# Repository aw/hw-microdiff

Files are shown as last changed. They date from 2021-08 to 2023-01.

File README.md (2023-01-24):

# μDiff: 10mbps over 1km on a single pair of wires

A simple 46mmx22.5mm module to route power and differential signals (RS-485) over RJ-45.

Stacked modules

This project is also described in detail [on Hackaday.io](https://hackaday.io/project/179020-10mbps-over-1km-on-a-single-pair-of-wires)

It can be purchased as a kit **[from Tindie](https://www.tindie.com/products/24510/)**

 

This project is [certified open hardware](https://certification.oshwa.org/jp000009.html):

OSHW_mark_JP000009 (https://certification.oshwa.org/jp000009.html)

# How it works

μDiff provides an easy way to reliably transfer power and a digital signal over a long-distance using an inexpensive RJ-45 cable.

[Watch a demo](
https://www.youtube.com/watch?v=i-OBXi-Fx-U)

It uses RS-485 differential signaling and 802.3af Power-over-Ethernet pinouts to achieve this. It can accept an input voltage between 6.5V-12V, and provides outputs of 5V and 3.3V. All signals and voltages can be accessed through a 10-pin header. 

Current is limited to 1A. Beware of current limitations on the RJ-45 cable, it's typically ~350mA for an AWG26 shielded wire. 

# PCB features

  * Form factor 46mm x 22.5mm
  * Lead-free, RoHS compliant
  * Stackable with 4xM2 holes (1x grounded)
  * Open Source Hardware under [CC BY-SA 4.0](#License)
  * Easy to source off-the-shelf through-hole components
  * On-board (SMD 0603, 0805) capacitors, resistors, and diodes
  * Solder bridge jumpers to enable fail-safe biasing, termination, grounding.

board-v05

### Top view

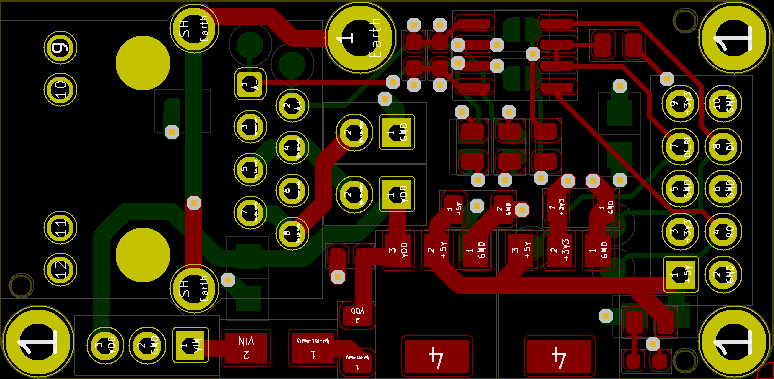
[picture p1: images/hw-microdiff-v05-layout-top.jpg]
PCB Top


### Bottom view

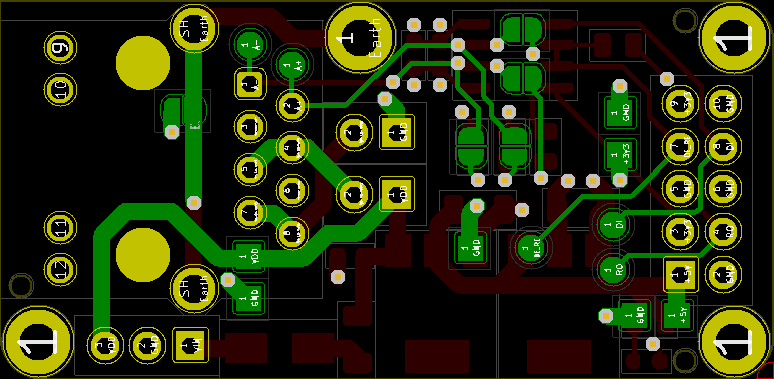
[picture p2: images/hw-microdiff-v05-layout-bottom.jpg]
PCB Bottom


See [images](images/) for more views.

# BOM (through-hole)

| Quantity | Item and Description | Datasheet |
| :----: | :---- | :---- |
| 1 | RJ45 Connector | [Assmann-RJ45-connector.pdf](datasheets/Assmann-RJ45-connector.pdf) |
| 1 | 10-pin (2x5) 2.54mm male of female header | |
| 1 | 3-pin (1x3) 2.54mm male or female header | |

# BOM (surface mount)

See [datasheets](datasheets/)

# Schematic

The schematic is available [here](schematic-v05.pdf)

# Notes

This PCB was designed with [Kicad](https://kicad.org/) v6.0 from the `debian buster-backports` repository.

I take no responsibility for any problems that may occur with your use of this PCB or design files. Create and use at your own risk.

# License

μDiff: 10mbps over 1km on a single pair of wires © 2021~ by [Alexander Williams](https://a1w.ca/) is licensed under [_CC BY-SA 4.0_ (Attribution-ShareAlike 4.0 International)](https://creativecommons.org/licenses/by-nc-sa/4.0/).

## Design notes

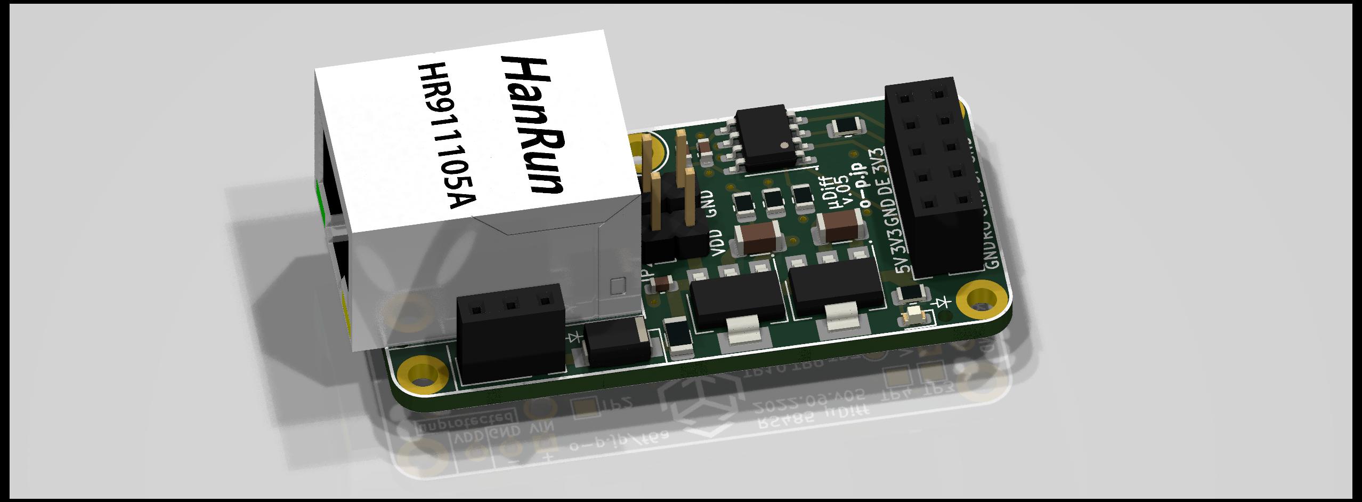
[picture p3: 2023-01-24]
images/hw-microdiff-v05-raytrace2.jpg

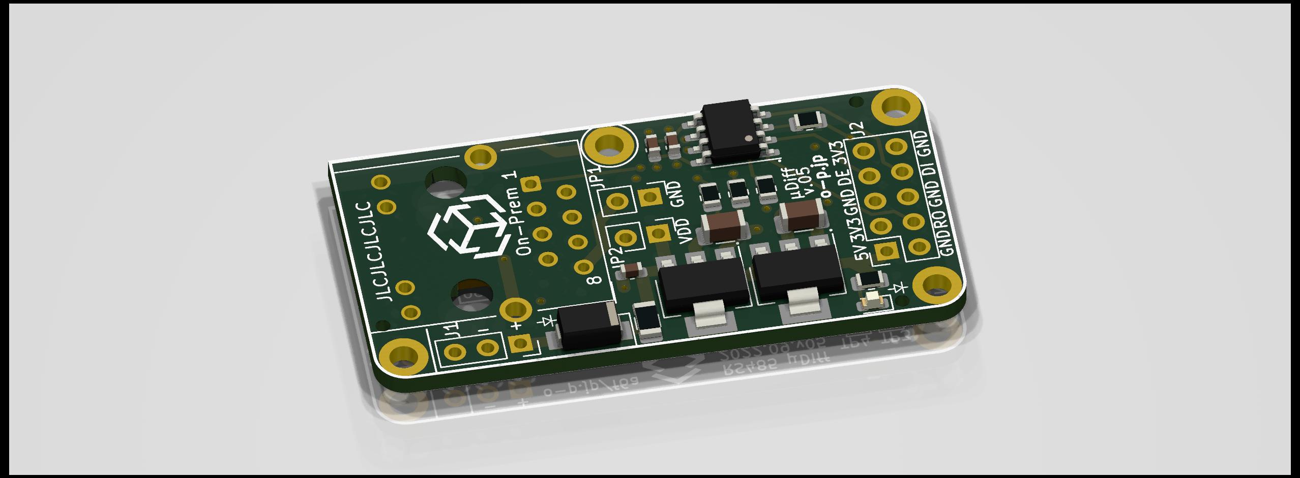
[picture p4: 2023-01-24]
images/hw-microdiff-v05-raytrace1.jpg

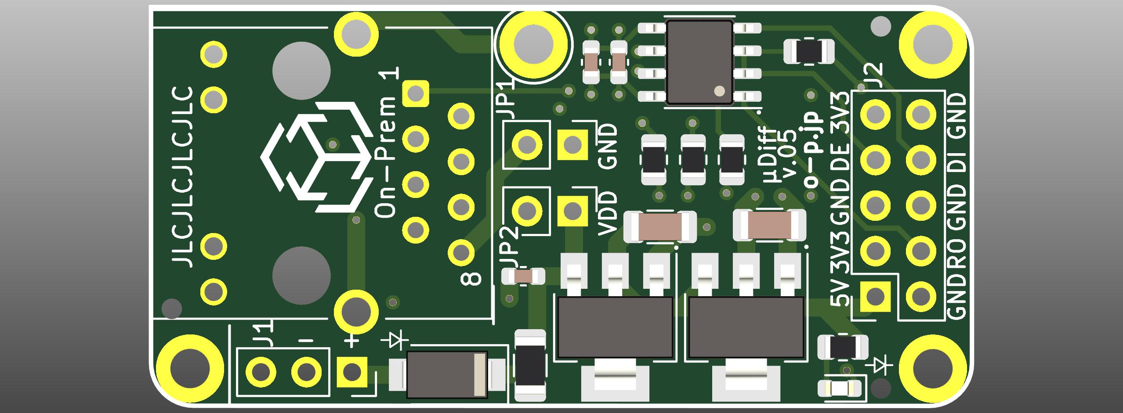
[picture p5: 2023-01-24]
images/hw-microdiff-v05-top-smd.jpg

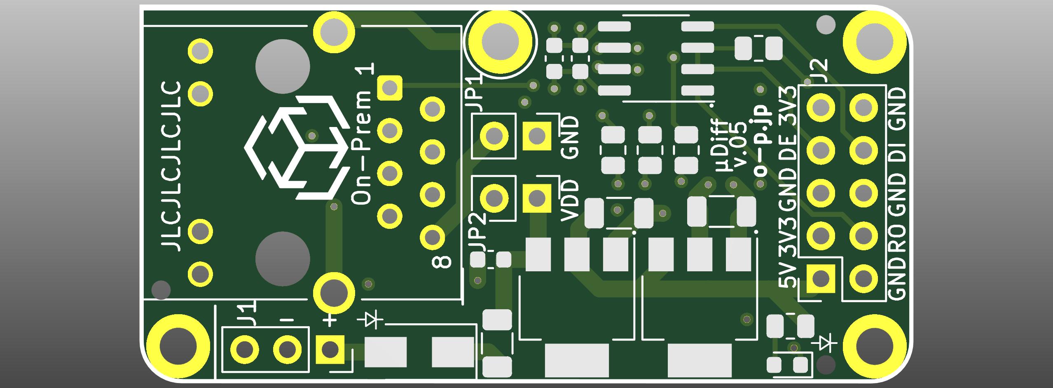
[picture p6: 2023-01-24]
images/hw-microdiff-v05-top.jpg

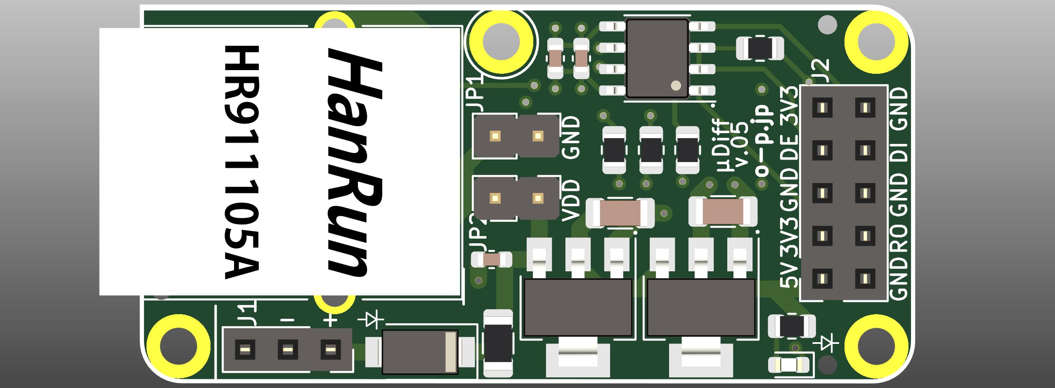
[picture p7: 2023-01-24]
images/hw-microdiff-v05-top-tht-smd.jpg

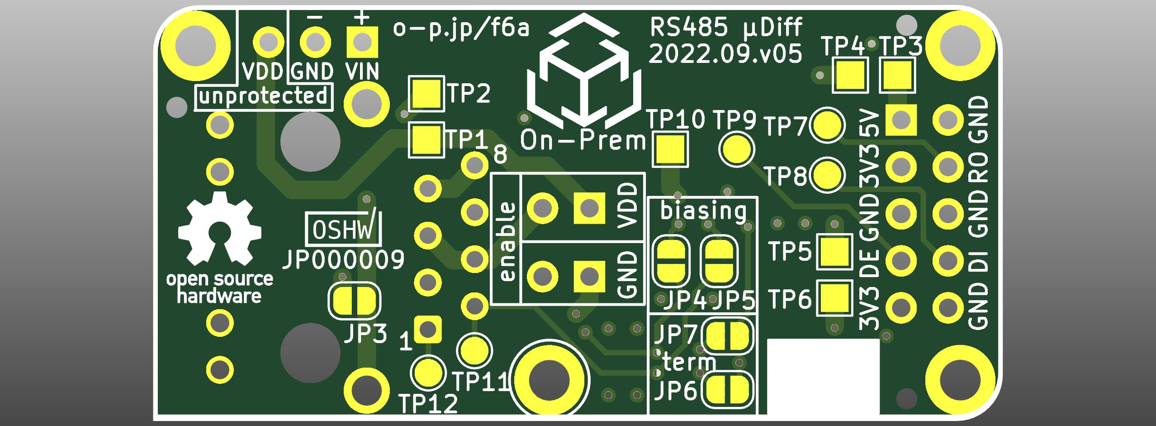
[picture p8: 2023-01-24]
images/hw-microdiff-v05-bottom.jpg

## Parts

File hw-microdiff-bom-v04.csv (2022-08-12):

Comment | Designator | Footprint | LCSC Part #
0.1uF 50V Unpolarized capacitor | C1,C4 | C_0603_1608Metric | C14663
22uF 10V Unpolarized capacitor | C2,C3 | C_1206_3216Metric | C5672
10uF 10V Unpolarized capacitor | C5 | C_0603_1608Metric | C19702
Diode 40V/3A Schottky diode | D1 | D_SMA | C8678
Blue LED Light emitting diode | D2 | LED_0603_1608Metric | C72041
Fuse 24V/1A Fuse | F1 | Fuse_1206_3216Metric | C910830
M3_MountingHole Mounting Hole without connection | H2,H3,H4 | MountingHole_2.2mm_M2_ISO14580_Pad
Power Input Generic connector, single row, 01x02, script generated (kicad-library-utils/schlib/autogen/connector/) | J1 | PinHeader_1x02_P2.54mm_Vertical
Header 2x4P Generic connector, double row, 02x04, odd/even pin numbering scheme (row 1 odd numbers, row 2 even numbers), script generated (kicad-library-utils/schlib/autogen/connector/) | J2 | PinSocket_2x04_P2.54mm_Vertical
8P8C RJ connector, 8P8C (8 positions 8 connected), RJ31/RJ32/RJ33/RJ34/RJ35/RJ41/RJ45/RJ49/RJ61, Shielded | J3 | RJ45_Hanrun_HR911105A
GND EN Jumper, normally open, small symbol | JP1 | PinHeader_1x02_P2.54mm_Vertical
VIN EN Jumper, normally open, small symbol | JP2 | PinHeader_1x02_P2.54mm_Vertical
drive EN Jumper, normally open, small symbol | JP3 | SW_DIP_SPSTx01_Slide_9.78x4.72mm_W7.62mm_P2.54mm
220R Resistor | R1 | R_0805_2012Metric | C17557
10K Resistor | R2,R4,R6,R8 | R_0805_2012Metric
20K Resistor | R3,R7 | R_0805_2012Metric_Pad1.20x1.40mm_HandSolder
120R Resistor | R5 | R_Axial_DIN0207_L6.3mm_D2.5mm_P10.16mm_Horizontal
5V/1A 1A Low Dropout regulator, positive, 5.0V fixed output, SOT-223 | U1 | SOT-223 | C6187
3.3V/1A 1A Low Dropout regulator, positive, 3.3V fixed output, SOT-223 | U2 | SOT-223 | C6186
RS-485 Industrial 3.3V Low Power Half-Duplex RS-485 Transceiver 10Mbps, SOIC-8 | U3 | SOIC-8_3.9x4.9mm_P1.27mm | C8963

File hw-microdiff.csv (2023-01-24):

Comment | Designator | Footprint | LCSC Part #
0.1uF 50V Unpolarized capacitor | C1,C4 | C_0603_1608Metric | C14663
22uF 10V Unpolarized capacitor | C2,C3 | C_1206_3216Metric | C5672
10uF 10V Unpolarized capacitor | C5 | C_0603_1608Metric | C19702
Diode 40V/3A Schottky diode | D1 | D_SMA | C8678
Blue LED Light emitting diode | D2 | LED_0603_1608Metric | C72041
Fuse 24V/1A Fuse | F1 | Fuse_1206_3216Metric | C910830
M2_MountingHole Mounting Hole without connection | H1,H2,H3,H4 | MountingHole_2.2mm_M2_ISO14580_Pad
Power Input Generic connector, single row, 01x03, script generated (kicad-library-utils/schlib/autogen/connector/) | J1 | PinSocket_1x03_P2.54mm_Vertical
Header 2x5P Generic connector, double row, 02x05, odd/even pin numbering scheme (row 1 odd numbers, row 2 even numbers), script generated (kicad-library-utils/schlib/autogen/connector/) | J2 | PinSocket_2x05_P2.54mm_Vertical
8P8C RJ connector, 8P8C (8 positions 8 connected), RJ31/RJ32/RJ33/RJ34/RJ35/RJ41/RJ45/RJ49/RJ61, Shielded | J3 | RJ45_Hanrun_HR911105A
GND EN Jumper, 2-pole, open | JP1 | PinHeader_1x02_P2.54mm_Vertical
VIN EN Jumper, 2-pole, open | JP2 | PinHeader_1x02_P2.54mm_Vertical
Grounding Solder Jumper, 2-pole, open | JP3 | SolderJumper-2_P1.3mm_Open_RoundedPad1.0x1.5mm
Biasing- Solder Jumper, 2-pole, open | JP4 | SolderJumper-2_P1.3mm_Open_RoundedPad1.0x1.5mm
Biasing+ Solder Jumper, 2-pole, open | JP5 | SolderJumper-2_P1.3mm_Open_RoundedPad1.0x1.5mm
Terminating Solder Jumper, 2-pole, open | JP6,JP7 | SolderJumper-2_P1.3mm_Open_RoundedPad1.0x1.5mm
220R Resistor | R1 | R_0805_2012Metric | C17557
10K Resistor | R2 | R_0805_2012Metric | C17414
390R Resistor | R3,R4 | R_0805_2012Metric | C17655
100R Resistor | R5 | R_0805_2012Metric | C17408
TP_VDD test point | TP1 | TestPoint_Pad_1.5x1.5mm
TP_GND test point | TP2,TP4,TP6,TP10 | TestPoint_Pad_1.5x1.5mm
TP_5V test point | TP3 | TestPoint_Pad_1.5x1.5mm
TP_3V3 test point | TP5 | TestPoint_Pad_1.5x1.5mm
TP_RO test point | TP7 | TestPoint_Pad_D1.5mm
TP_DI test point | TP8 | TestPoint_Pad_D1.5mm
TP_DE_RE test point | TP9 | TestPoint_Pad_D1.5mm
TP_A1 test point | TP11 | TestPoint_Pad_D1.5mm
TP_B1 test point | TP12 | TestPoint_Pad_D1.5mm
5V/1A 1A Low Dropout regulator, positive, 5.0V fixed output, SOT-223 | U1 | SOT-223 | C6187
3.3V/1A 1A Low Dropout regulator, positive, 3.3V fixed output, SOT-223 | U2 | SOT-223 | C6186
RS-485 Industrial 3.3V Low Power Half-Duplex RS-485 Transceiver 10Mbps, SOIC-8 | U3 | SOIC-8_3.9x4.9mm_P1.27mm | C8963

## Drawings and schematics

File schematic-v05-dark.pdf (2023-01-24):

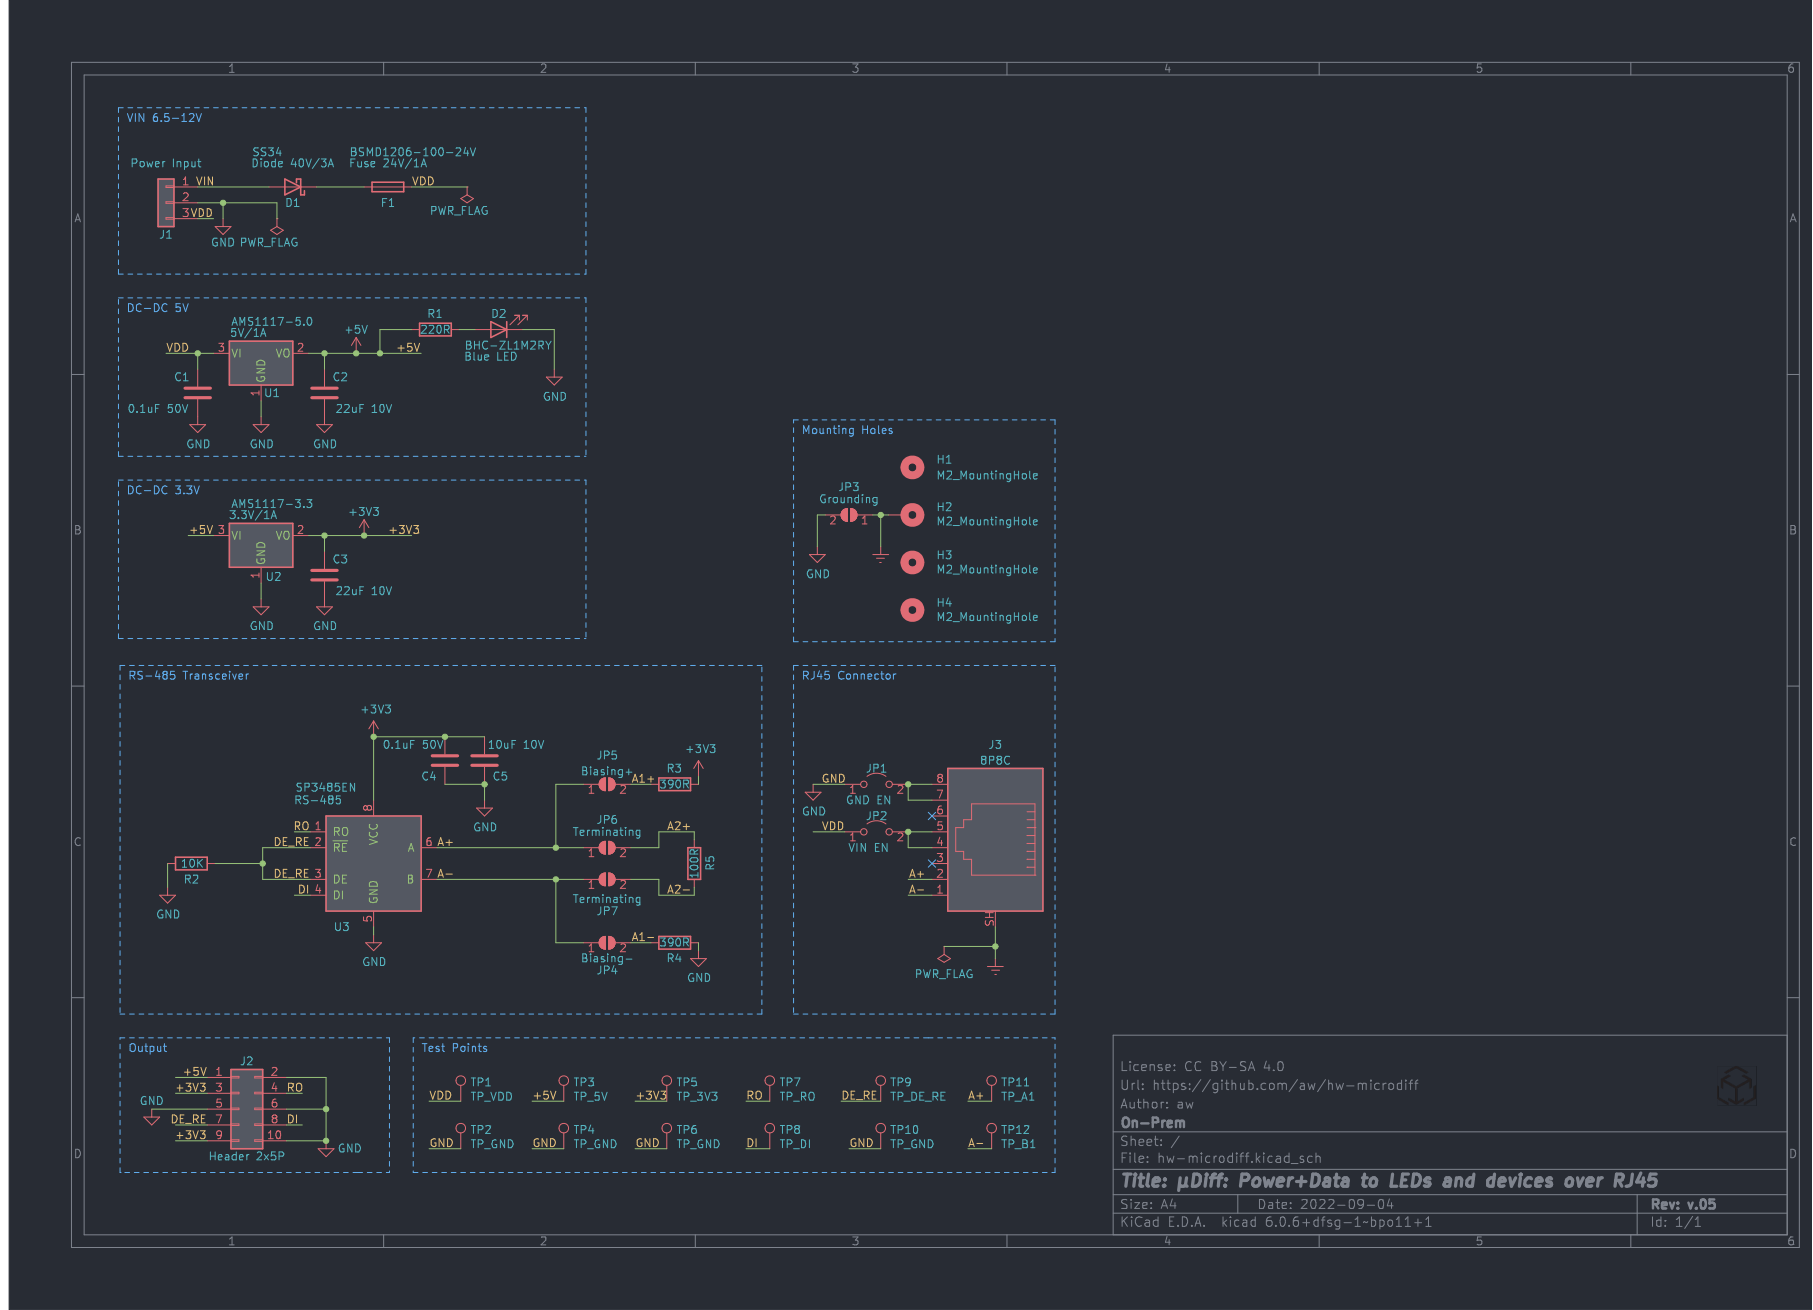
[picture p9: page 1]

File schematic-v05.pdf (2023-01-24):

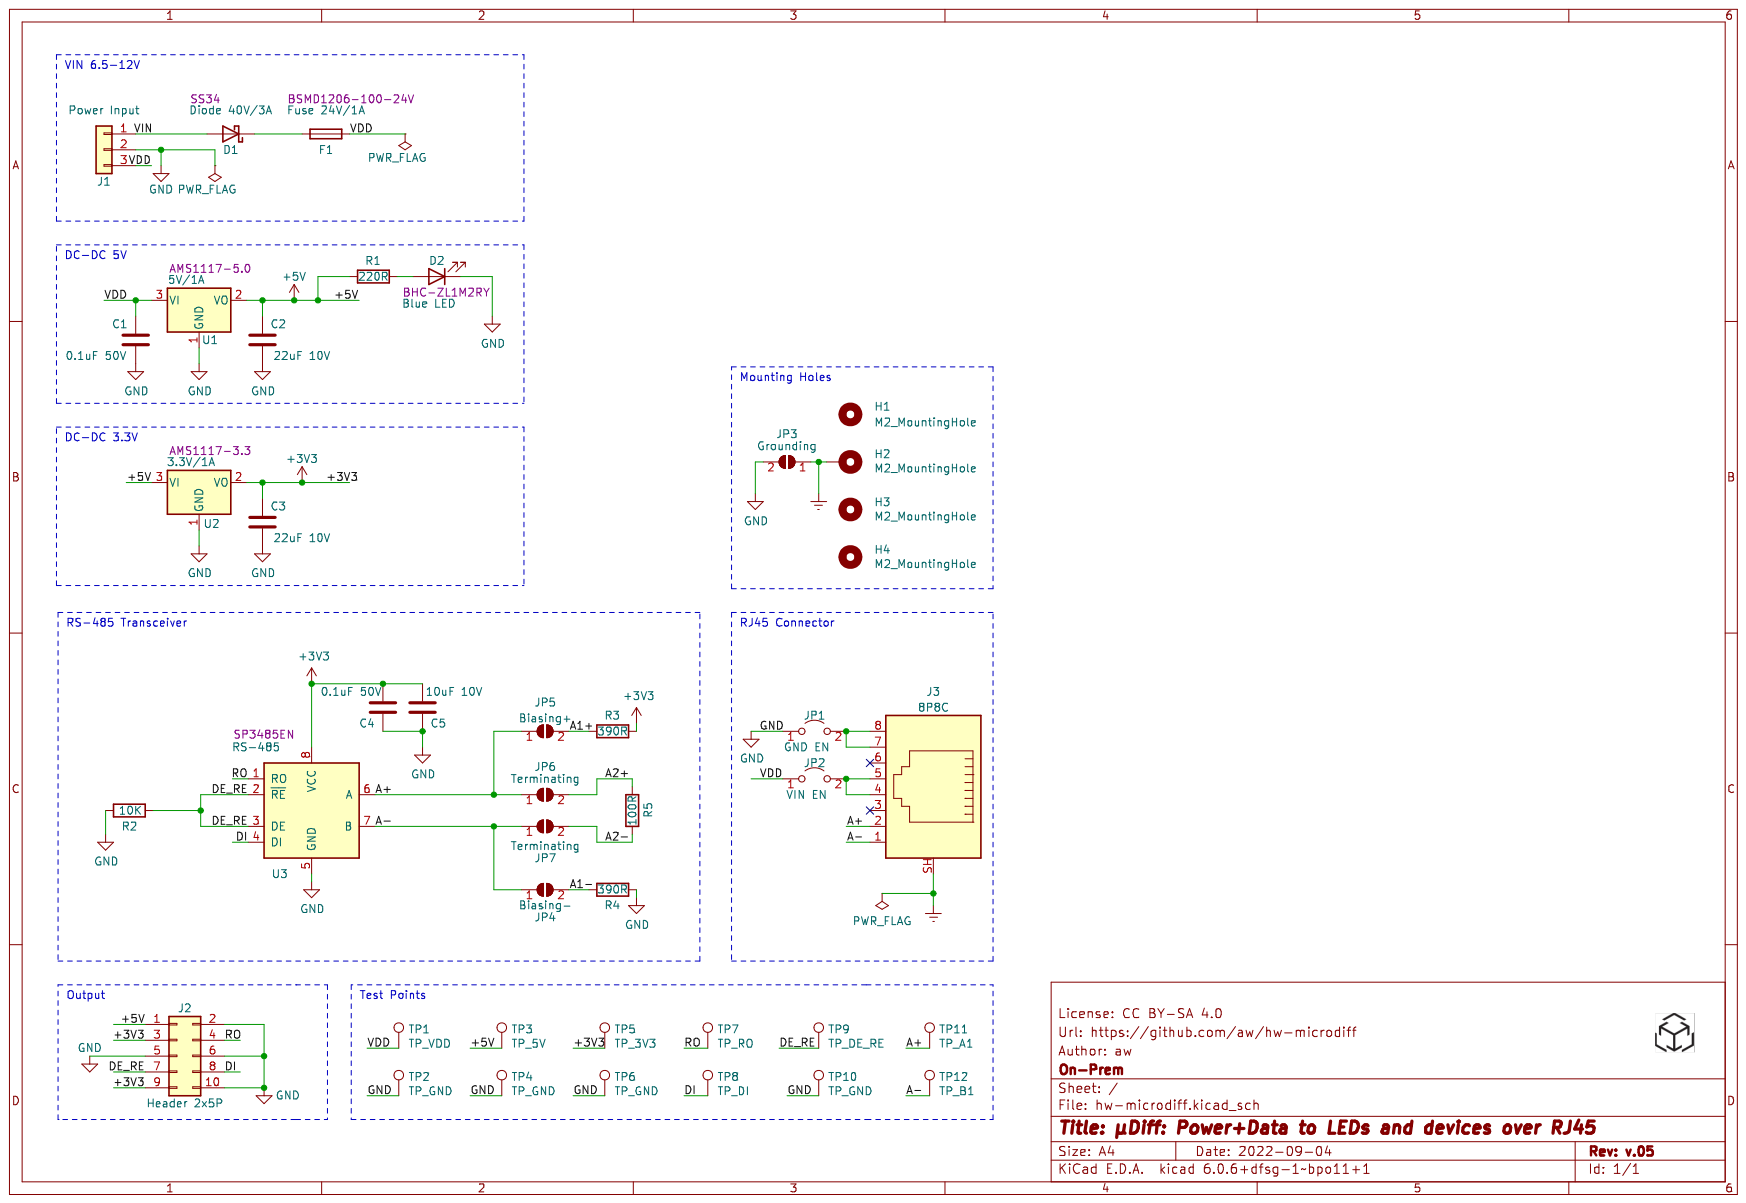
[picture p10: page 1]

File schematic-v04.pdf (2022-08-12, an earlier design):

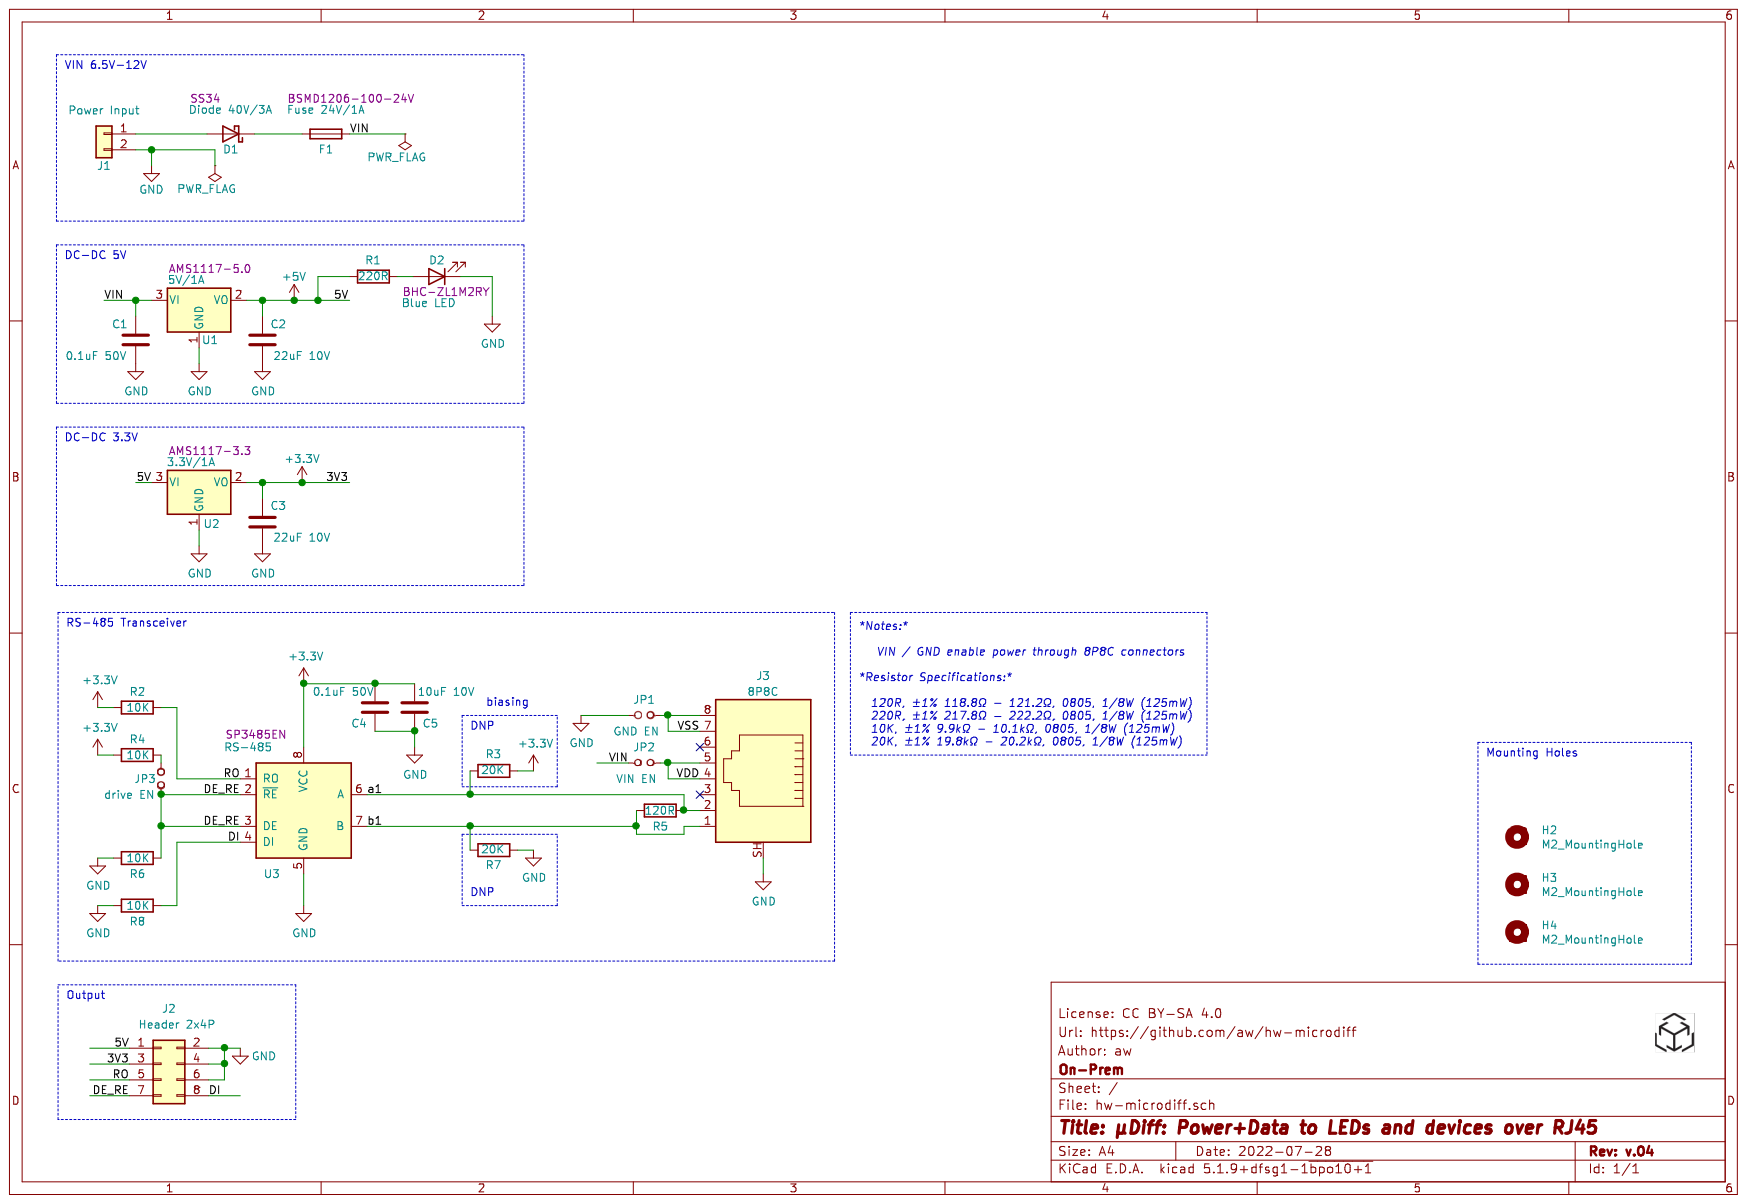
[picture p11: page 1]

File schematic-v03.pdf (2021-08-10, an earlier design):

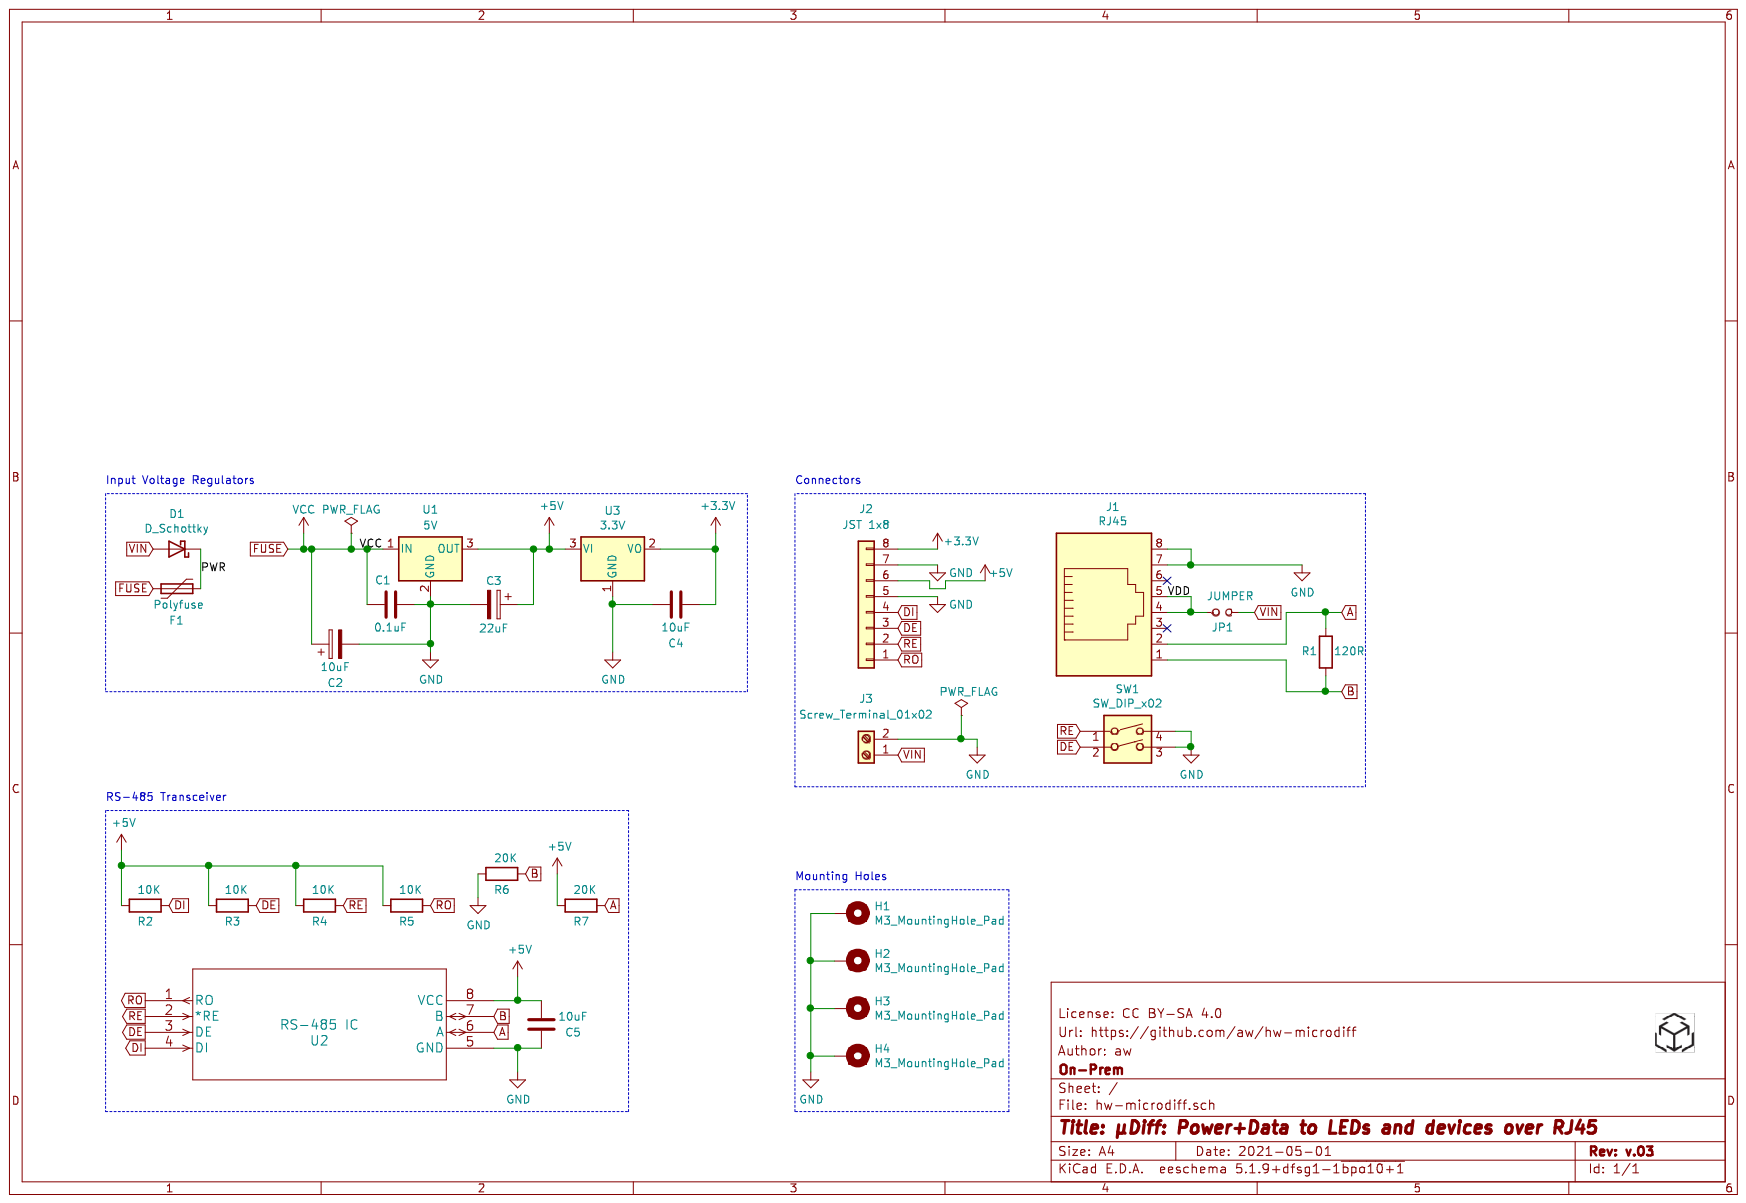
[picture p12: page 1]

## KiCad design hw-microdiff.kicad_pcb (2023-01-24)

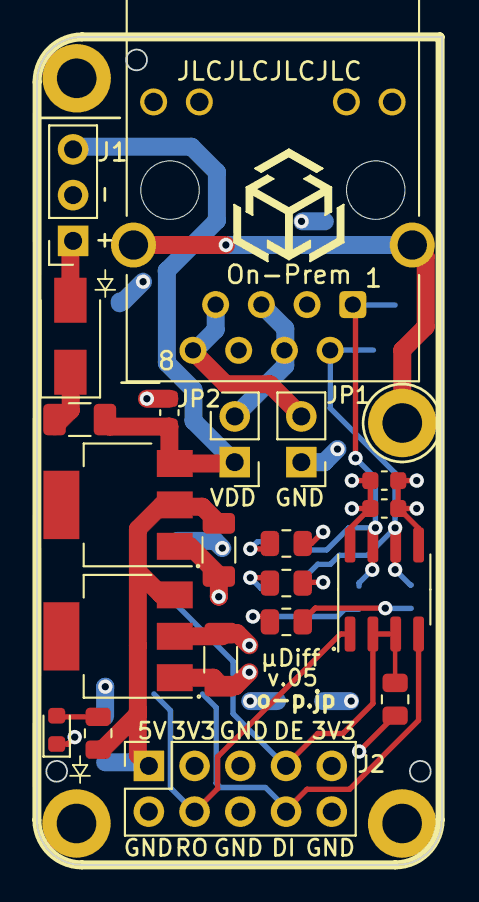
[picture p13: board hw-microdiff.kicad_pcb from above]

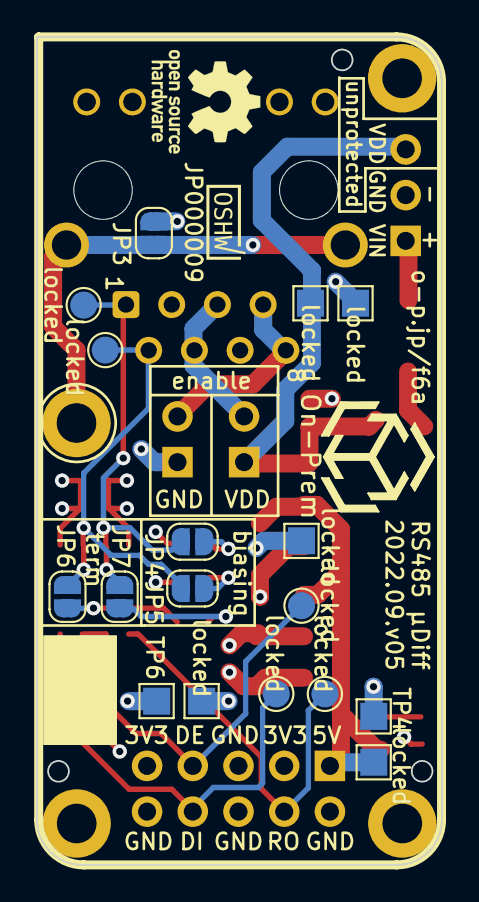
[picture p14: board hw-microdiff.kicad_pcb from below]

Board: 4 copper layers, 22.5 x 46.0 mm, 43 parts (18 on the bottom side), 19 nets.

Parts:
C1, C4: 0.1uF 50V; C_0603_1608Metric
C2, C3: 22uF 10V; C_1206_3216Metric
C5: 10uF 10V; C_0603_1608Metric
D1: Diode 40V/3A; D_SMA
D2: Blue LED; LED_0603_1608Metric
F1: Fuse 24V/1A; Fuse_1206_3216Metric
H1, H2, H3, H4: M2_MountingHole; MountingHole_2.2mm_M2_ISO14580_Pad
J1: Power Input; PinSocket_1x03_P2.54mm_Vertical
J2: Header 2x5P; PinSocket_2x05_P2.54mm_Vertical
J3: 8P8C; RJ45_Hanrun_HR911105A
JP1: GND EN; PinHeader_1x02_P2.54mm_Vertical
JP2: VIN EN; PinHeader_1x02_P2.54mm_Vertical
JP3: Grounding; SolderJumper-2_P1.3mm_Open_RoundedPad1.0x1.5mm
JP4: Biasing-; SolderJumper-2_P1.3mm_Open_RoundedPad1.0x1.5mm
JP5: Biasing+; SolderJumper-2_P1.3mm_Open_RoundedPad1.0x1.5mm
JP6, JP7: Terminating; SolderJumper-2_P1.3mm_Open_RoundedPad1.0x1.5mm
OSHW_Mono_0.1_Scale: JP000009; OSHW_Mono_0.1_Scale
R1: 220R; R_0805_2012Metric
R2: 10K; R_0805_2012Metric
R3, R4: 390R; R_0805_2012Metric
R5: 100R; R_0805_2012Metric
TP4, TP6: TP_GND; TestPoint_Pad_1.5x1.5mm
U1: 5V/1A; SOT-223
U2: 3.3V/1A; SOT-223
U3: RS-485; SOIC-8_3.9x4.9mm_P1.27mm
locked: TP_VDD; TestPoint_Pad_1.5x1.5mm
locked#2, locked#8: TP_GND; TestPoint_Pad_1.5x1.5mm
locked#3: TP_5V; TestPoint_Pad_1.5x1.5mm
locked#4: TP_3V3; TestPoint_Pad_1.5x1.5mm
locked#5: TP_RO; TestPoint_Pad_D1.5mm
locked#6: TP_DI; TestPoint_Pad_D1.5mm
locked#7: TP_DE_RE; TestPoint_Pad_D1.5mm
locked#9: TP_A1; TestPoint_Pad_D1.5mm
locked#10: TP_B1; TestPoint_Pad_D1.5mm

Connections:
+3V3: C3.2, C4.1, C5.1, J2.3, J2.9, R3.2, U2.2 (VO), U3.8 (VCC), locked#4.1
+5V: C2.1, J2.1, R1.1, U1.2 (VO), U2.3 (VI), locked#3.1
/A1+: JP5.2 (B), R3.1
/A1-: JP4.2 (B), R4.1
/A2+: JP6.2 (B), R5.1
/A2-: JP7.2 (B), R5.2
/A+: J3.2, JP5.1 (A), JP6.1 (A), U3.6 (A), locked#9.1
/A-: J3.1, JP4.1 (A), JP7.1 (A), U3.7 (B), locked#10.1
/DE_RE: J2.7, R2.1, U3.2 (~RE), U3.3 (DE), locked#7.1
/DI: J2.8, U3.4 (DI), locked#6.1
/RO: J2.4, U3.1 (RO), locked#5.1
/VDD: C1.1, F1.2, J1.3, JP2.1 (A), U1.3 (VI), locked.1
/VIN: D1.2 (A), J1.1
Earth: H2.1, J3.SH, JP3.1 (A)
GND: C1.2, C2.2, C3.1, C4.2, C5.2, D2.1 (K), J1.2, J2.2, J2.5, J2.6, J2.10, JP1.1 (A), JP3.2 (B), R2.2, R4.2, TP4.1, TP6.1, U1.1 (GND), U2.1 (GND), U3.5 (GND), locked#2.1, locked#8.1
unnamed: D1.1 (K), F1.1
unnamed: D2.2 (A), R1.2
unnamed: J3.4, J3.5, JP2.2 (B)
unnamed: J3.7, J3.8, JP1.2 (B)

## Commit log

2021-08-05 Add README and schematic
2021-08-10 Add design files and update license
    [hw-microdiff.kicad_pcb, hw-microdiff.sch]
2021-08-12 Add BOM for through-hole components
2022-08-12 Finish PCB routing for v.04
    [hw-microdiff.csv, hw-microdiff.kicad_pcb, hw-microdiff.sch]
2023-01-24 Minor layout corrections: - Add test pads on back of PCB - Remove 10K pullup - Adjust silkscreens - Update to KiCad 6.0 - Add 3D model for RJ45 connector - Add VDD pin for unprotected VIN - Add open 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
    [hw-microdiff-bom-v03.csv, hw-microdiff-bom-v04.csv, hw-microdiff.csv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]

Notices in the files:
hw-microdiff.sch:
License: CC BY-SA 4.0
